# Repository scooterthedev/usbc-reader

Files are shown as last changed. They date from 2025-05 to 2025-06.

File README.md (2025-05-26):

# Powdy

Powdy is an all-in-one power reader via USB-C! Just plug it in to your device, and watch as the power draw reading come onto the OLED screen. This device mostly uses one main component to read the power- The INA226, along with the MCU- the ATmega328P-A.

## Software 
The whole software is being written in Arduino (yes, I know....), and being flashed to the MCU via a USBtinyISP as a HEX file via SPI, and the 6 pin headers on-board.

## BOM
| Item Name | Purpose in Project | Source | Item Price (incl. shipping + taxes) | Total Price |
|---|---|---|---|---|
| USB-C | What connects to the device to read the power output | JLC - C165948 | $0.84 | $0.84 |
| OLED| For displaying the reading | Amazon | $7.93 | $7.93 |
| Caps and Resistors x 14| For everything | JLC | $0.29 | $0.29 |
| 2x03 Pin Header| For programming | Digikey - 61300411121 | $0.34 | $0.34 |
| INA226 | the actual IC to measure the power going through the USB-C port | JLC - C2653835 | $9.3 | $9.3 |
| AMS1117-3.3 | Voltage regulator to 3.3V from 5V for stuff like OLED and some INA226 pins | JLC - C6186 | $0.89 | $0.89 |
| ATmega328P-A | The Main MCU | JLC - C14877 | $11 | $11 |
| Crystal | For the MCU | Digi - ABM3-16.000MHZ-B2-T | $0.9 | $0.9 |
| USBtinyISP| The board to program the MCU via the 6 header pins | Amazon | $1 | $11 |
**Total**        - **$43 Before Tax In Parts**
**Total** - **$117 After Everything including assembly + pcb + tax and shipping**

## Photos




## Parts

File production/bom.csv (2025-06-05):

Designator | Footprint | Quantity | Value | LCSC Part #
BRD1 | Adafruit_SSD1306 | 1 | SSD1306
C1, C2 | 0603 | 2 | 10 µF
C3, C4 | 0603 | 2 | 22 pF
C5 | 0603 | 1 | 1µF
C6 | 0603 | 1 | 0.1 µF
J1 | USB_C_Receptacle_GCT_USB4105-xx-A_16P_TopMnt_Horizontal | 1 | USB_C_Receptacle
J2 | Tag-Connect_TC2030-IDC-NL_2x03_P1.27mm_Vertical | 1 | AVR-ISP-6
J3 | TerminalBlock_4Ucon_1x02_P3.50mm_Horizontal | 1 | Screw_Terminal_01x02
R1, R2, R5, R6 | 0603 | 4 | 4.7kΩ
R3, R4 | 0603 | 2 | 5.1kΩ
R7 | 0603 | 1 | 0.05 Ω
R9 | 0603 | 1 | 10kΩ
U1 | VSSOP-10_3x3mm_P0.5mm | 1 | INA226
U2 | SOT-223-3_TabPin2 | 1 | AMS1117-3.3
U3 | TQFP-32_7x7mm_P0.8mm | 1 | ATmega328P-A
Y1 | Crystal_SMD_0603-2Pin_6.0x3.5mm | 1 | Crystal

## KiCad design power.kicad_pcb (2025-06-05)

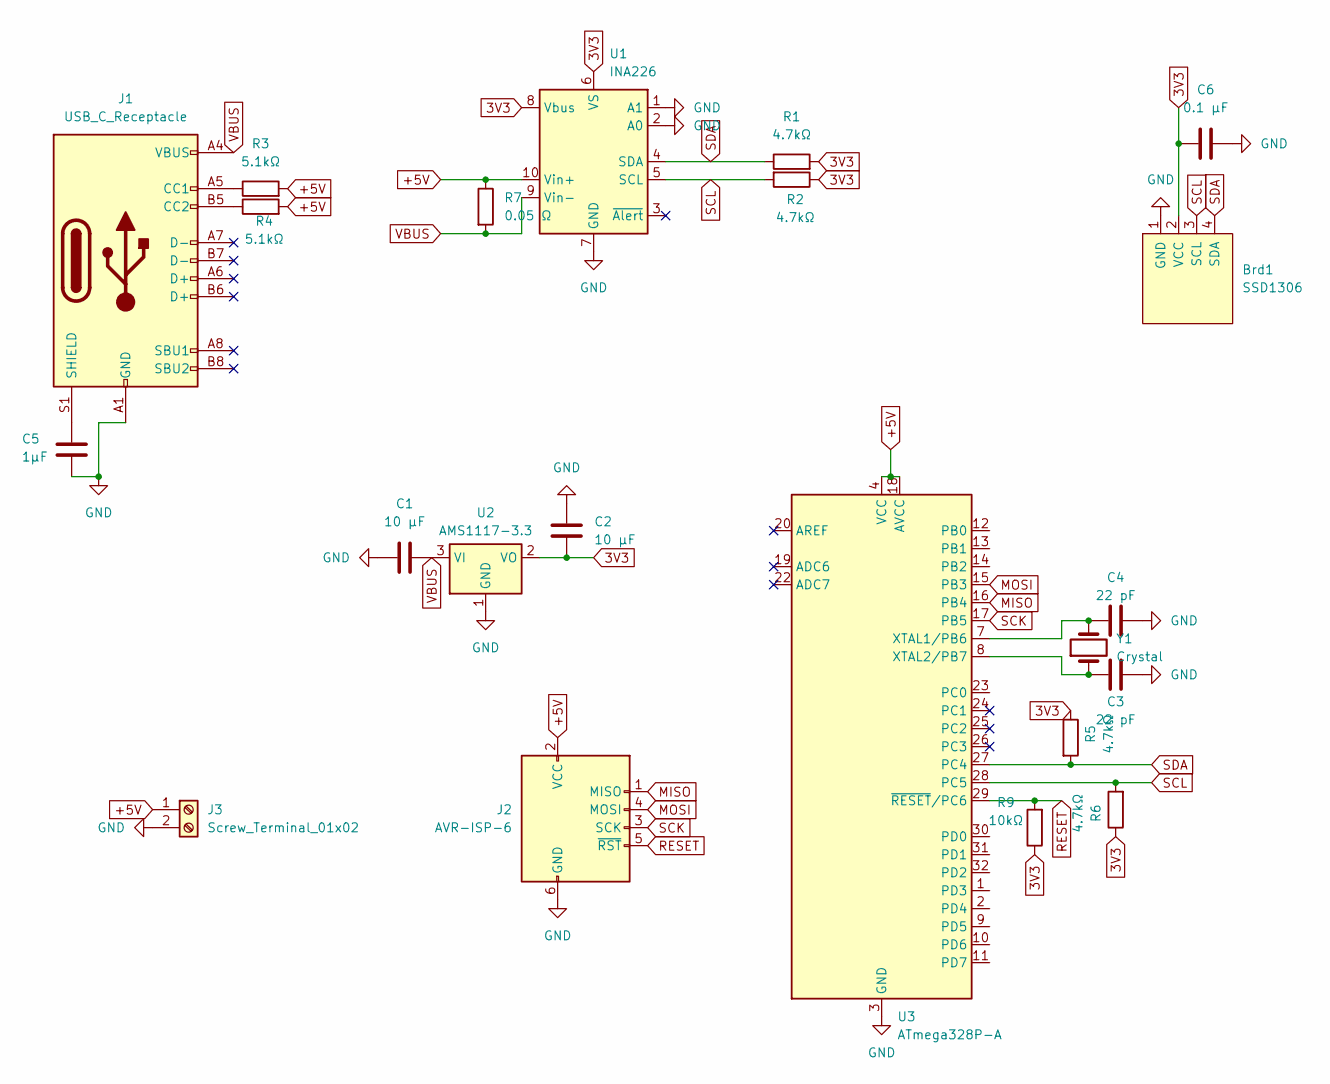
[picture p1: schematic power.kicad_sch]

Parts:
Brd1: SSD1306; Adafruit_SSD1306
C1, C2: 10 µF; C_0603_1608Metric
C3, C4: 22 pF; C_0603_1608Metric
C5: 1µF; C_0603_1608Metric
C6: 0.1 µF; C_0603_1608Metric
J1: USB_C_Receptacle; USB_C_Receptacle_Amphenol_124019772112A
J2: AVR-ISP-6; Tag-Connect_TC2030-IDC-NL_2x03_P1.27mm_Vertical
J3: Screw_Terminal_01x02; TerminalBlock_4Ucon_1x02_P3.50mm_Horizontal
R1, R2, R5, R6: 4.7kΩ; R_0603_1608Metric
R3, R4: 5.1kΩ; R_0603_1608Metric
R7: 0.05 Ω; R_0603_1608Metric
R9: 10kΩ; R_0603_1608Metric
U1: INA226; VSSOP-10_3x3mm_P0.5mm
U2: AMS1117-3.3; SOT-223-3_TabPin2
U3: ATmega328P-A; TQFP-32_7x7mm_P0.8mm
Y1: Crystal; Crystal_SMD_0603-2Pin_6.0x3.5mm

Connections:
3V3: Brd1.2 (VCC), C2.1, C6.1, R1.2, R2.1, R5.1, R6.1, R9.1, U1.6 (VS), U1.8 (Vbus), U2.2 (VO)
+5V: J2.2 (VCC), J3.1, R3.2, R4.2, R7.1, U1.10 (Vin+), U3.4 (VCC), U3.6 (VCC), U3.18 (AVCC)
GND: Brd1.1 (GND), C1.1, C2.2, C3.2, C4.2, C5.2, C6.2, J1.A1 (GND), J1.A12 (GND), J1.B1 (GND), J1.B12 (GND), J2.6 (GND), J3.2, U1.1 (A1), U1.2 (A0), U1.7 (GND), U2.1 (GND), U3.3 (GND), U3.5 (GND), U3.21 (GND)
MISO: J2.1 (MISO), U3.16 (PB4)
MOSI: J2.4 (MOSI), U3.15 (PB3)
unnamed: J1.A5 (CC1), R3.1
unnamed: J1.B5 (CC2), R4.1
unnamed: C5.1, J1.S1 (SHIELD)
unnamed: C4.1, U3.7 (XTAL1/PB6), Y1.2
unnamed: C3.1, U3.8 (XTAL2/PB7), Y1.1
RESET: J2.5 (~RST), R9.2, U3.29 (~RESET/PC6)
SCK: J2.3 (SCK), U3.17 (PB5)
SCL: Brd1.3 (SCL), R2.2, R6.2, U1.5 (SCL), U3.28 (PC5)
SDA: Brd1.4 (SDA), R1.1, R5.2, U1.4 (SDA), U3.27 (PC4)
VBUS: C1.2, J1.A4 (VBUS), J1.A9 (VBUS), J1.B4 (VBUS), J1.B9 (VBUS), R7.2, U1.9 (Vin-), U2.3 (VI)

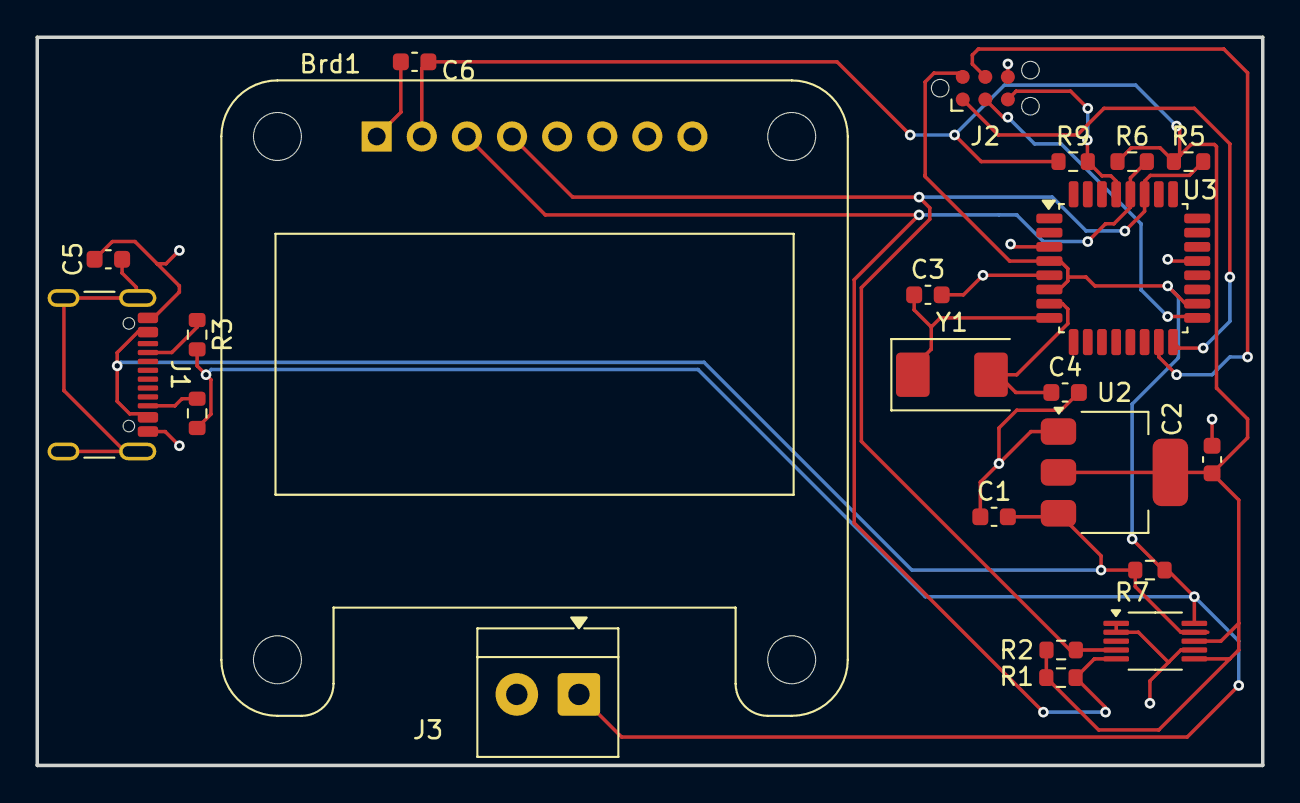
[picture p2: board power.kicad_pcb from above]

Board: 2 copper layers, 69.0 x 41.0 mm, 22 parts (0 on the bottom side), 15 nets.

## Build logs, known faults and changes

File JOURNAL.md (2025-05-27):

**Day 1 - Saturday night into Sunday - 6 hours**

This is my first day that I started to work on this project. I wanted to make a device that could measure power draw from a usb-c compatible device. I did a majority of the work on this day. I gathered all the parts that I needed for it which includes a usb-c port obviously ;), a INA226 for power measuring, and it all running on a ATmega328P-A displayed on a OLED screen via II2. I did multiple things in order

- I built the Schematic for it including figuring out how to wire up the INA226 
	
	- Also, figured out OLED issues via IIC and the needed crystal (ended up needing to be 16MHZ with 2 22pF caps!)
- Routed 95% of the PCB ;)
	- I spent most of the night (all the way up until 4am!) routing all the traces on my 2 layer PCB. I probably spent close to 2-2.5 hours straight routing it all! My biggest struggle was figuring out how to put it all in a small-ish form factor while all being on the front. Lots of vias later- I got it mostly done for the night.
	

For the rest of Sunday, I didn't continue to work on this as I had other projects to work on 👀. 

**Day 2 - Monday - 3.5 hours**

Today was mostly just double checking everything, and making sure there were no issues (Suprise! There were a few that I fixed, like SMD pin headers 🤦‍♂️, and OLED footprints). Next I pretty much was on a mission to find all the nessecary components for my BOM- which was super annoying especially for the Crystal as there was none I could buy off of LCSC (I need to buy it, and find it from Digikey :(). Once I finally found all the right components, I submitted my project to Highway as the full PCB was done along with the BOM.

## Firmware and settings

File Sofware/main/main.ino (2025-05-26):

#include <Wire.h>
#include <INA226.h>
#include <Adafruit_GFX.h>
#include <Adafruit_SSD1306.h>

// OLED display configuration
#define SCREEN_WIDTH 128
#define SCREEN_HEIGHT 64
Adafruit_SSD1306 display(SCREEN_WIDTH, SCREEN_HEIGHT, &Wire, -1);

INA226 ina;

void setup() {
  Serial.begin(9600);
  Wire.begin();

  // initialize the OLED screen
  if (!display.begin(SSD1306_SWITCHCAPVCC, 0x3C)) {
    Serial.println("OLED not found!");
    while (1);
  }

  display.clearDisplay();
  display.setTextSize(1);
  display.setTextColor(SSD1306_WHITE);

  // initialize the INA226
  if (ina.begin() != 0) {
    Serial.println("INA226 not found! Go fix it!!");
    display.setCursor(0, 0);
    display.println("INA226 not working :(");
    display.display();
    while (1);
  }

  // here we are configuring conversion times and averaging ( to improve accuracy (hopefully))
  ina.setAverage(INA226_AVERAGES_16); // smooth out readings
  ina.setBusConversionTime(INA226_CONV_TIME_1100US);
  ina.setShuntConversionTime(INA226_CONV_TIME_1100US);
  ina.setMode(INA226_MODE_CONTINUOUS);

  display.setCursor(0, 0);
  display.println("INA226 is working! Yay!");
  display.display();
  delay(1000);
}

void loop() {
  float voltage = ina.readBusVoltage();  // in V
  float current = ina.readCurrent();     // in mA
  float power   = ina.readPower();       // in mW

  // print the details to serial
  Serial.print("Voltage: "); Serial.print(voltage, 2); Serial.println(" V");
  Serial.print("Current: "); Serial.print(current, 1); Serial.println(" mA");
  Serial.print("Power:   "); Serial.print(power, 1); Serial.println(" mW");
  Serial.println();

  // display the details on the OLED
  display.clearDisplay();
  display.setCursor(0, 0);
  display.print("Voltage: "); display.print(voltage, 2); display.println(" V");
  display.print("Current: "); display.print(current, 1); display.println(" mA");
  display.print("Power:   "); display.print(power, 1); display.println(" mW");
  display.display();

  delay(1000);
}

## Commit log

2025-05-25 Initial parts
    [power.kicad_sch]
2025-05-25 Getting there
    [power.kicad_sch]
2025-05-25 Added custom OLED, finished small changes to the schematic, and started the PCB
    [power.kicad_pcb, power.kicad_sch]
2025-05-25 PCB Routing Starting
    [power.kicad_pcb, power.kicad_sch]
2025-05-25 Schematic 95% done
    [power.kicad_pcb]
2025-05-25 Small DRC Fixes
    [power.kicad_pcb]
2025-05-25 Switched to 5V over 3.3V for MCU for programming
    [power.kicad_pcb, power.kicad_sch]
2025-05-25 Small PCB changes
    [power.kicad_pcb]
2025-05-26 Finished it all!
    [bom.csv, designators.csv, positions.csv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]
2025-05-28 Possibly fixed it
    [power.kicad_pcb, power.kicad_sch]
2025-05-28 Got the corruption gone via a backup!!
    [power.kicad_pcb]
2025-05-28 Fixed the few small changes from my revert
    [power.kicad_pcb]
2025-06-04 Final fixes
    [bom.csv, designators.csv, positions.csv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]
2025-06-05 Switched USB C out to the proper one
    [bom.csv, positions.csv, power.kicad_pcb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]
